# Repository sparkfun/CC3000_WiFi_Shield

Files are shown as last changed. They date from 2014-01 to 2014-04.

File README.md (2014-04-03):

CC3000_WiFi_Shield
====================

[TI CC3000 WiFi Shield  
*CC3000 WiFi Shield (WRL-12071)*](https://www.sparkfun.com/products/12071)

Arduino WiFi shield for the [TI CC3000 module](http://www.ti.com/product/cc3000). The datasheet can be found [here](http://www.ti.com/lit/ds/symlink/cc3000.pdf).

Arduino library and examples can be found in the [SFE_CC3000_Library](https://github.com/sparkfun/SFE_CC3000_Library).

This part was created in Eagle v6.5.0. Example sketches were created in Arduino v1.0.5.

Repository Contents
-------------------

* **/Hardware** - All Eagle design files (.brd, .sch, .STL)
* **/Production** - Test bed files and production panel files

Version History
---------------
* **v1.0** Initial release

License Information
-------------------
The hardware is released under [Creative Commons Share-alike 3.0](http://creativecommons.org/licenses/by-sa/3.0/).  
All other code is open source so please feel free to do anything you want with it; you buy me a beer if you use this and we meet someday ([Beerware license](http://en.wikipedia.org/wiki/Beerware)).

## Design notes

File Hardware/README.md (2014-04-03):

# What Are these Files?

The .sch and .brd files hare are Eagle CAD schematic and PCB design files.

These files were created with Eagle 6.5.0, you'll need Eagle 6.5 or later to open them up. There is a free, lite, version of Eagle available from [cadsoftusa.com](cadsoftusa.com).

# License

This product is open source! These Eagle files are released under the Creative Commons Share-Alike Attribution license ([CC BY-SA 3.0](http://creativecommons.org/licenses/by-sa/3.0/us/)).

Please use, reuse, and modify these files as you see fit. Please maintain attribution and release anything derivative under the same license.

- Your friends at SparkFun.

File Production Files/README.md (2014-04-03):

These are the production files SparkFun uses for printing PCBs, as well as the Eagle files for our test beds.

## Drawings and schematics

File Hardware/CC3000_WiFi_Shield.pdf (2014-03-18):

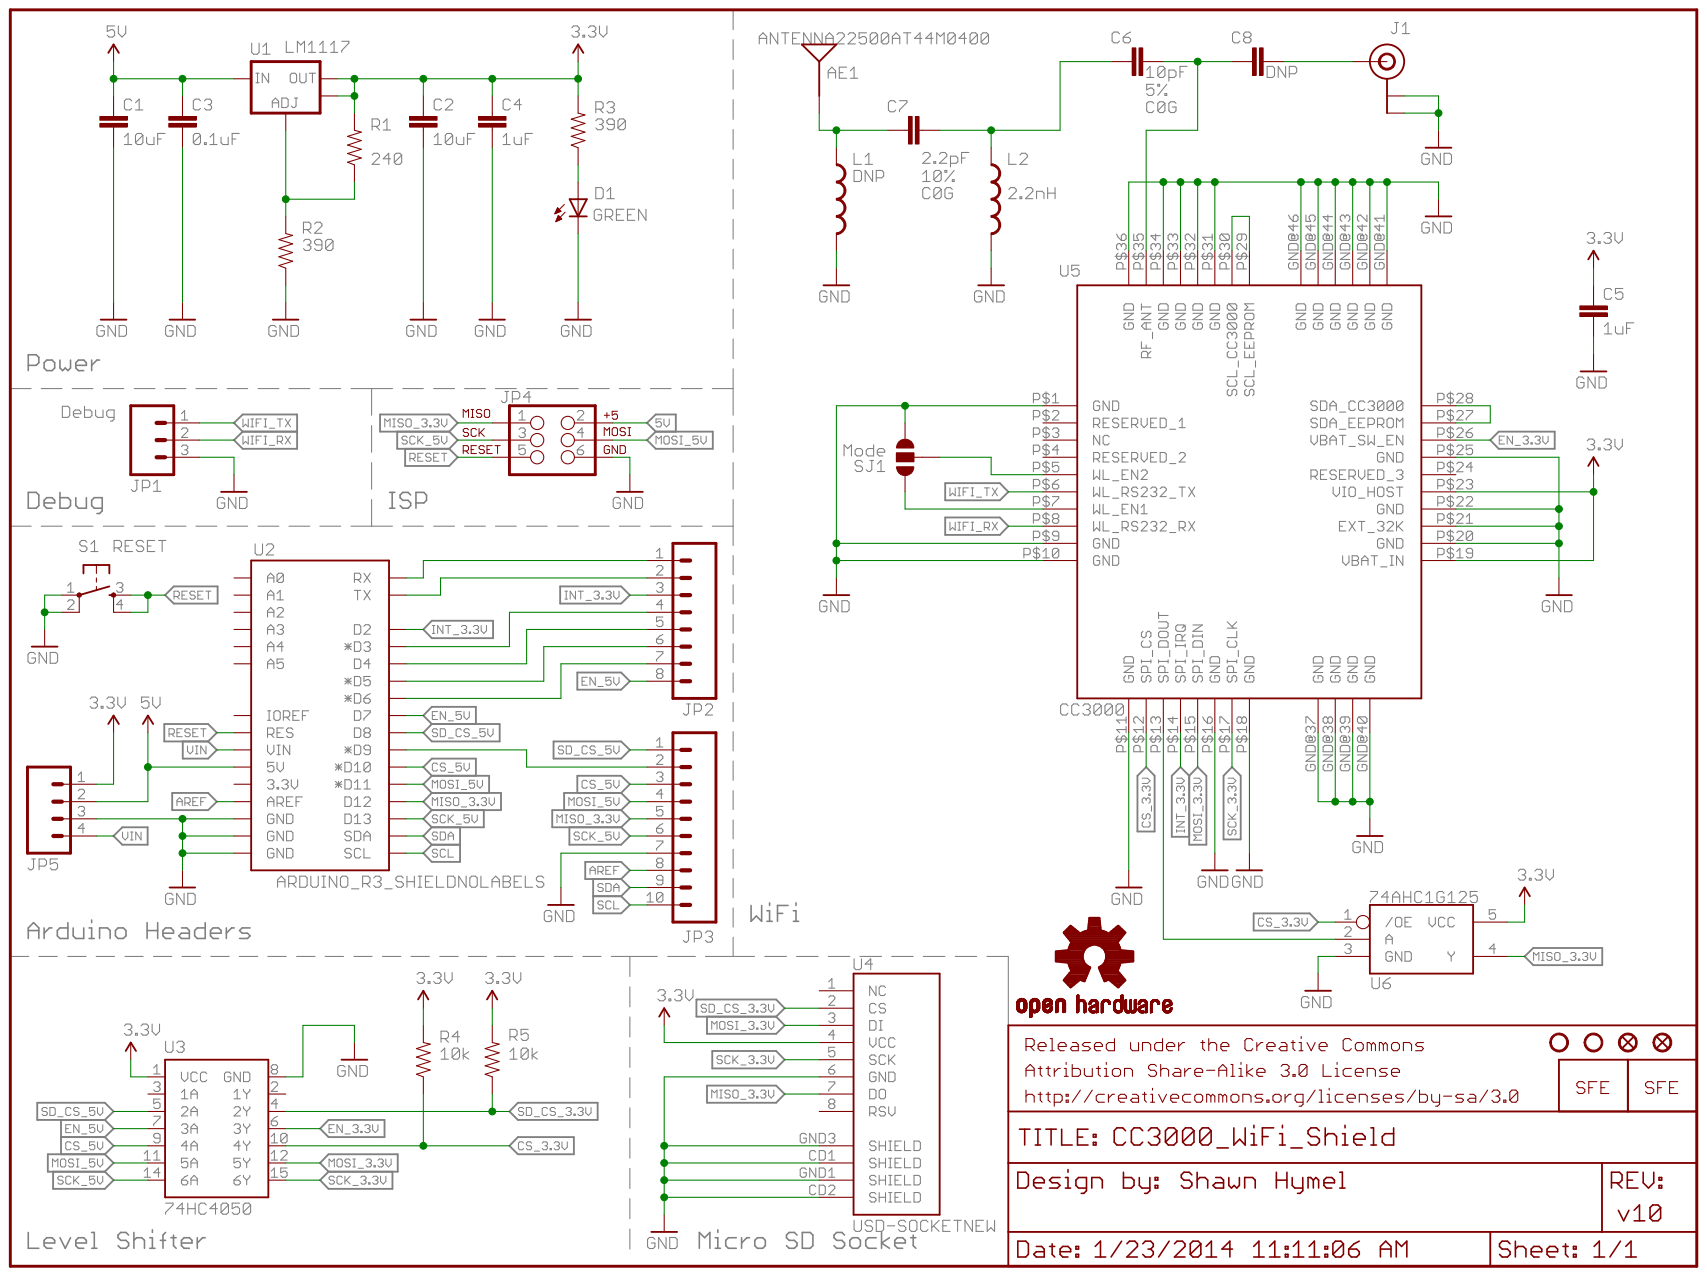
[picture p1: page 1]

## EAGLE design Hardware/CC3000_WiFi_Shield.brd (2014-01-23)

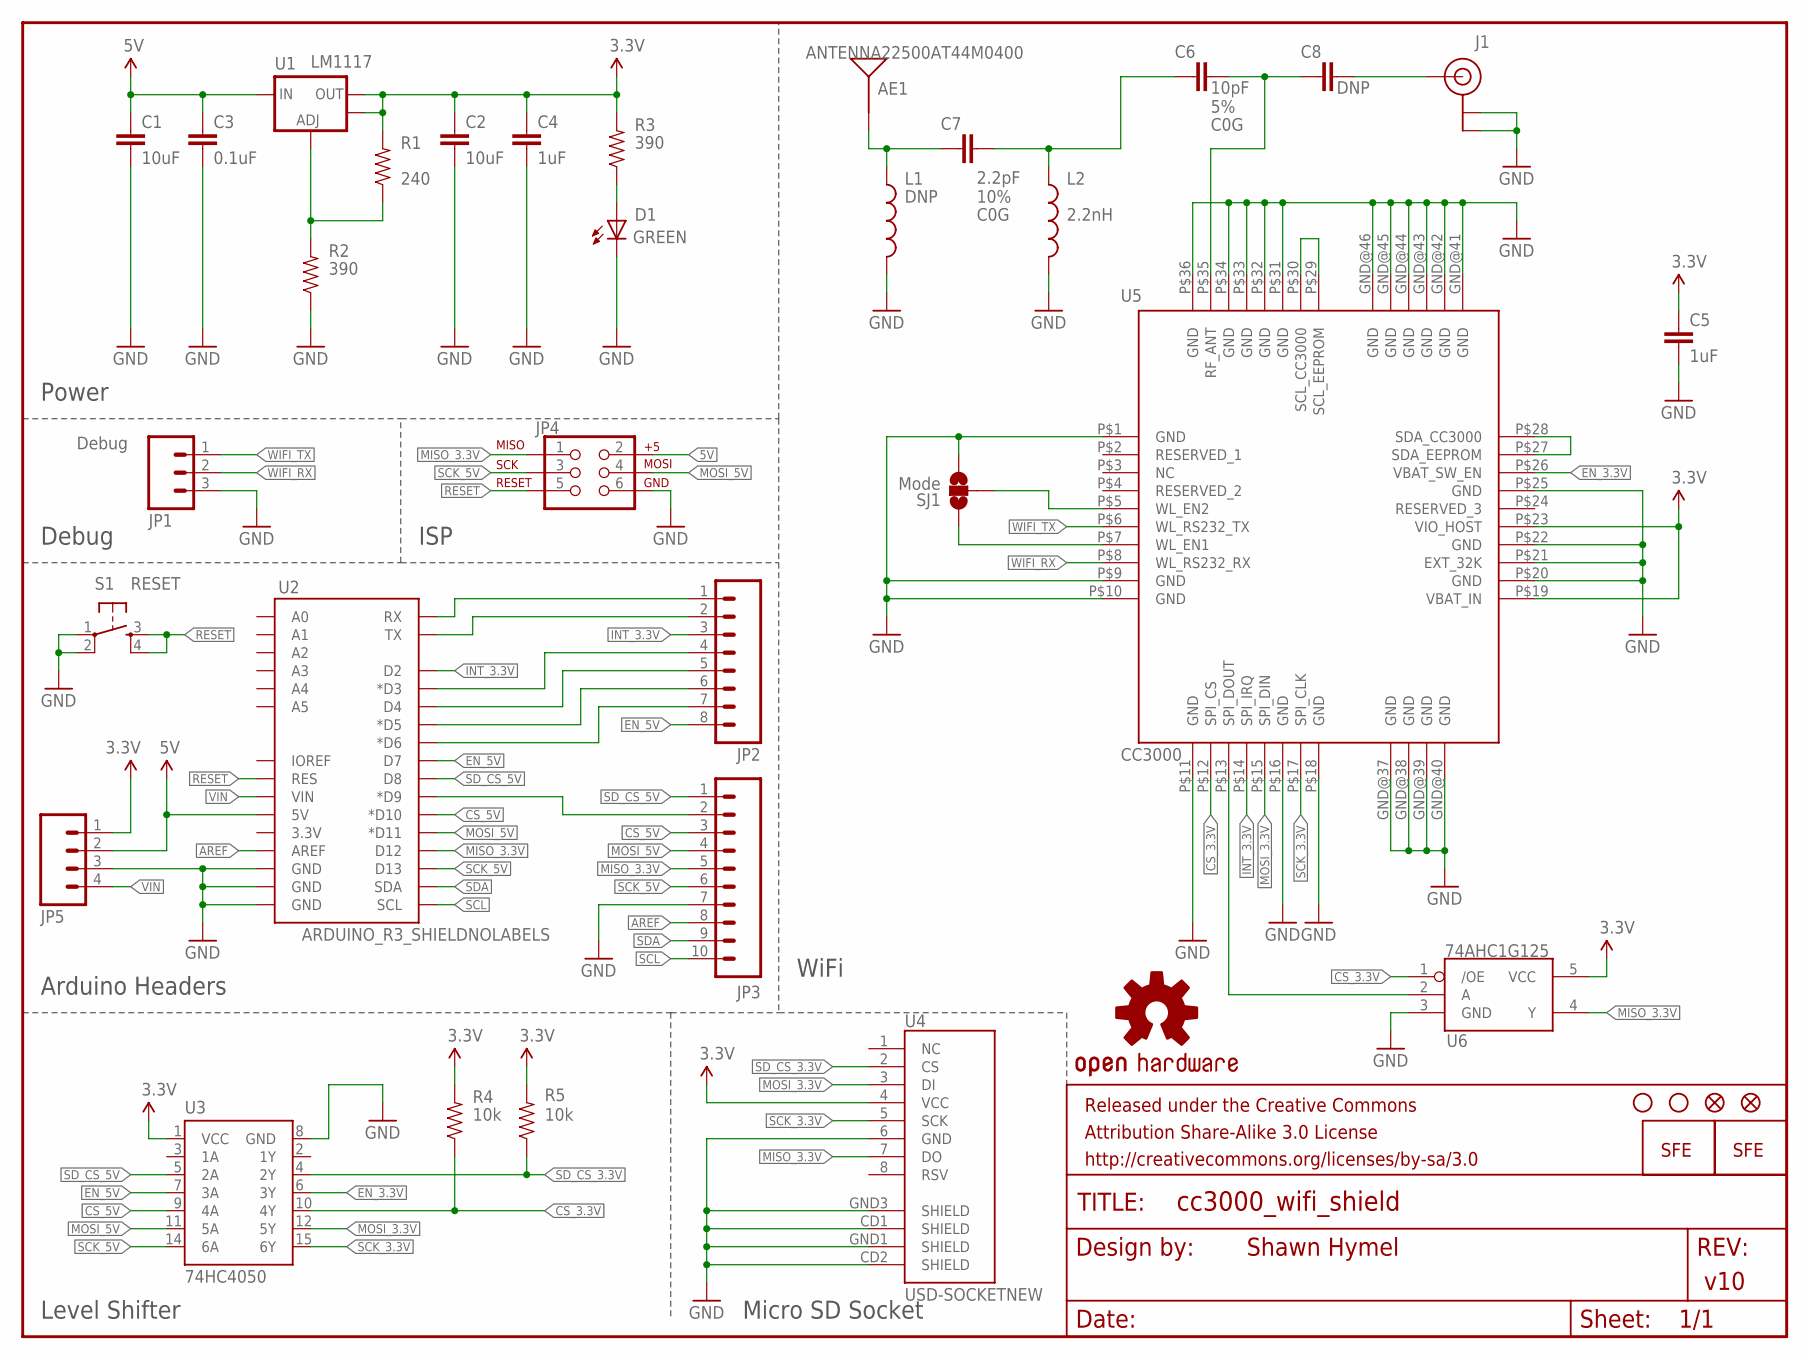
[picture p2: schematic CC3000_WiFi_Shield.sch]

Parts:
AE1: ANTENNA22500AT44M0400; ANTENNA-CHIP_2500AT44M0400
C1, C2: 10uF; 0805
C3: 0.1uF; 0603-CAP
C4, C5: 1uF; 0805
C6: 10pF; 0603-CAP
C7: 2.2pF; 0603-CAP
C8: DNP; 0603-CAP
D1: GREEN; LED-0603
FID1, FID2: FIDUCIAL1X2; FIDUCIAL-1X2
FRAME1: FRAME-LETTER; CREATIVE_COMMONS
J1: U.FL
JP1: Debug; 1X03
JP2: M08NO_SILK; 1X08_NO_SILK
JP3: M10NO_SILK; 1X10_NO_SILK
JP4: AVR_SPI_PRG_6PTH; 2X3
JP5: M04PTH; 1X04
L1: DNP; 0603
L2: 2.2nH; 0603
LOGO1: OSHW-LOGOS; OSHW-LOGO-S
LOGO2: LOGO-SFENEW; SFE-NEW-WEBLOGO
LOGO3: LOGO-SFESK; SFE-LOGO-FLAME
R1: 240; 0603-RES
R2, R3: 390; 0603-RES
R4, R5: 10k; 0603-RES
S1: RESET; TACTILE_SWITCH_SMD
SJ1: Mode; SJ_3_PASTE1&2
STANDOFF1, STANDOFF2: STAND-OFF
U1: LM1117; SOT223
U2: ARDUINO_R3_SHIELDNOLABELS; UNO_R3_SHIELD_NOLABELS
U3: 74HC4050; SO016
U4: USD-SOCKETNEW; MICRO-SD-SOCKET-PP
U5: CC3000; QFN-46_CC3000
U6: 74AHC1G125; SOT23-5

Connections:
3.3V: C2.1, C4.1, C5.1, JP5.1, R1.2, R3.2, R4.2, R5.2, U1.2 (OUT), U1.4 (OUT), U3.1 (VCC), U4.4 (VCC), U5.P$19 (VBAT_IN), U5.P$23 (VIO_HOST), U6.5 (VCC)
5V: C1.1, C3.1, JP4.2, JP5.2, U1.3 (IN), U2.5V
AREF: JP3.8, U2.AREF
CS_3.3V: R4.1, U3.10 (4Y), U5.P$12 (SPI_CS), U6.1 (/OE)
CS_5V: JP3.3, U2.D10 (*D10), U3.9 (4A)
EN_3.3V: U3.6 (3Y), U5.P$26 (VBAT_SW_EN)
EN_5V: JP2.8, U2.D7, U3.7 (3A)
GND: C1.2, C2.2, C3.2, C4.2, C5.2, D1.C, J1.P$1 (GND), J1.P$2 (GND), JP1.3, JP3.7, JP4.6, JP5.3, L1.2, L2.2, R2.1, S1.1, S1.2, SJ1.3, U2.GND@0 (GND), U2.GND@1 (GND), U2.GND@2 (GND), U3.8 (GND), U4.6 (GND), U4.CD1 (SHIELD), U4.CD2 (SHIELD), U4.GND1 (SHIELD), U4.GND3 (SHIELD), U5.GND@37 (GND), U5.GND@38 (GND), U5.GND@39 (GND), U5.GND@40 (GND), U5.GND@41 (GND), U5.GND@42 (GND), U5.GND@43 (GND), U5.GND@44 (GND), U5.GND@45 (GND), U5.GND@46 (GND), U5.P$1 (GND), U5.P$9 (GND), U5.P$10 (GND), U5.P$11 (GND), U5.P$16 (GND), U5.P$18 (GND), U5.P$20 (GND), U5.P$21 (EXT_32K), U5.P$22 (GND), U5.P$25 (GND), U5.P$31 (GND), U5.P$32 (GND), U5.P$33 (GND), U5.P$34 (GND), U5.P$36 (GND), U6.3 (GND)
INT_3.3V: JP2.3, U2.D2, U5.P$14 (SPI_IRQ)
MISO_3.3V: JP3.5, JP4.1, U2.D12, U4.7 (DO), U6.4 (Y)
MOSI_3.3V: U3.12 (5Y), U4.3 (DI), U5.P$15 (SPI_DIN)
MOSI_5V: JP3.4, JP4.4, U2.D11 (*D11), U3.11 (5A)
unnamed: R1.1, R2.2, U1.1 (ADJ)
unnamed: SJ1.2, U5.P$5 (WL_EN2)
unnamed: SJ1.1, U5.P$7 (WL_EN1)
unnamed: C6.1, C7.2, L2.1
unnamed: U5.P$27 (SDA_EEPROM), U5.P$28 (SDA_CC3000)
unnamed: U5.P$29 (SCL_EEPROM), U5.P$30 (SCL_CC3000)
unnamed: C6.2, C8.1, U5.P$35 (RF_ANT)
unnamed: C8.2, J1.P$3 (SIGNAL)
unnamed: AE1.FEED, C7.1, L1.1
unnamed: D1.A, R3.1
unnamed: JP2.1, U2.RX
unnamed: JP2.2, U2.TX
unnamed: JP2.4, U2.D3 (*D3)
unnamed: JP2.6, U2.D5 (*D5)
unnamed: JP2.7, U2.D6 (*D6)
unnamed: JP2.5, U2.D4
unnamed: JP3.2, U2.D9 (*D9)
RESET: JP4.5, S1.3, S1.4, U2.RES
SCK_3.3V: U3.15 (6Y), U4.5 (SCK), U5.P$17 (SPI_CLK)
SCK_5V: JP3.6, JP4.3, U2.D13, U3.14 (6A)
SCL: JP3.10, U2.SCL
SDA: JP3.9, U2.SDA
SD_CS_3.3V: R5.1, U3.4 (2Y), U4.2 (CS)
SD_CS_5V: JP3.1, U2.D8, U3.5 (2A)
VIN: JP5.4, U2.VIN
WIFI_MISO: U5.P$13 (SPI_DOUT), U6.2 (A)
WIFI_RX: JP1.2, U5.P$8 (WL_RS232_RX)
WIFI_TX: JP1.1, U5.P$6 (WL_RS232_TX)

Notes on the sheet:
Shawn Hymel
v10
Power
Debug
Arduino Headers
Level Shifter
Micro SD Socket
WiFi
ISP

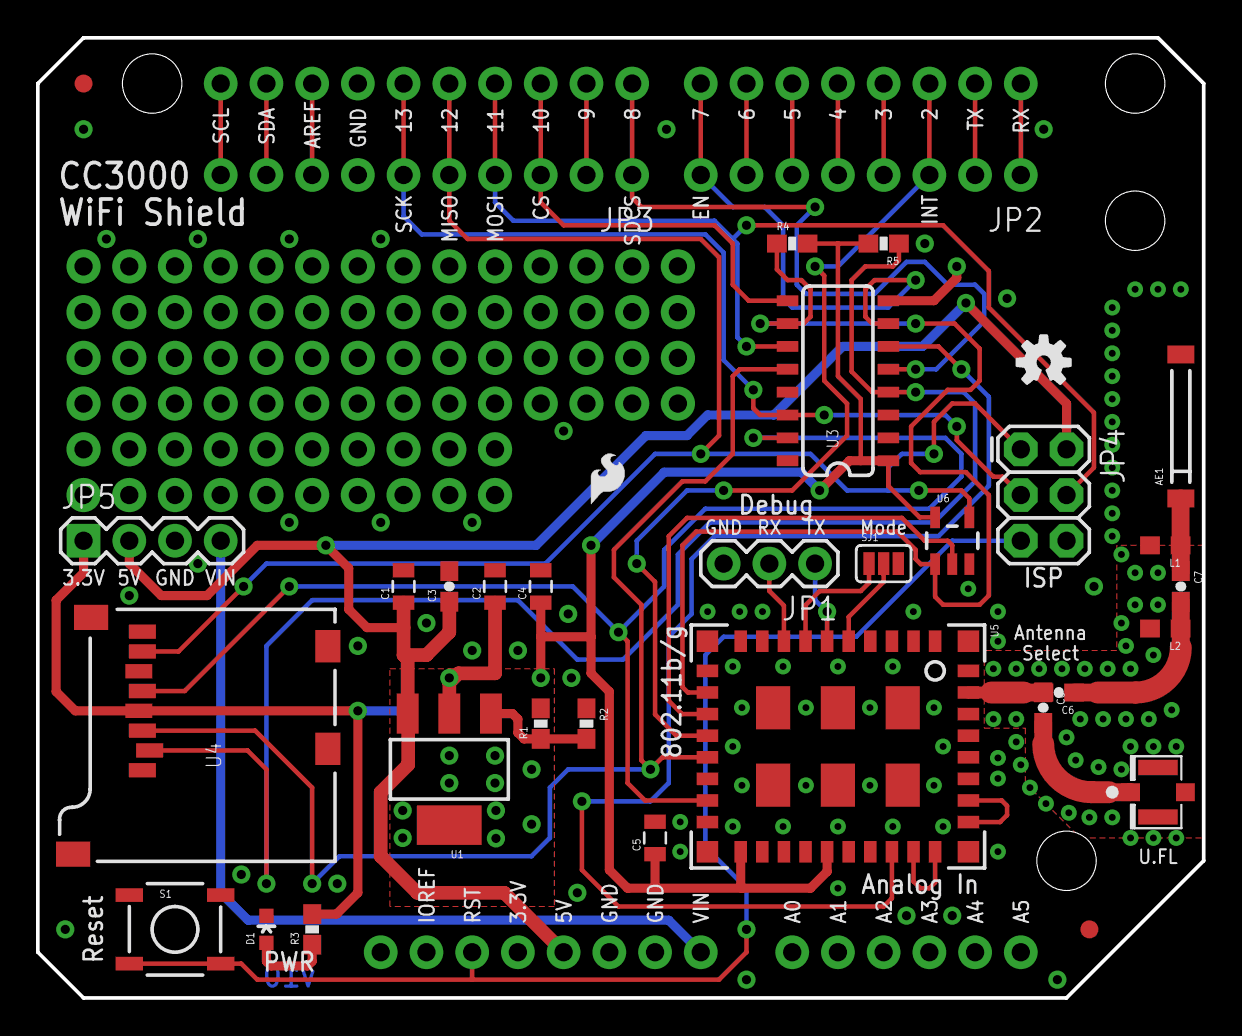
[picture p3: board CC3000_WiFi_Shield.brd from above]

Board: 2 copper layers, 64.8 x 53.3 mm, 39 parts (1 on the bottom side), 40 nets.

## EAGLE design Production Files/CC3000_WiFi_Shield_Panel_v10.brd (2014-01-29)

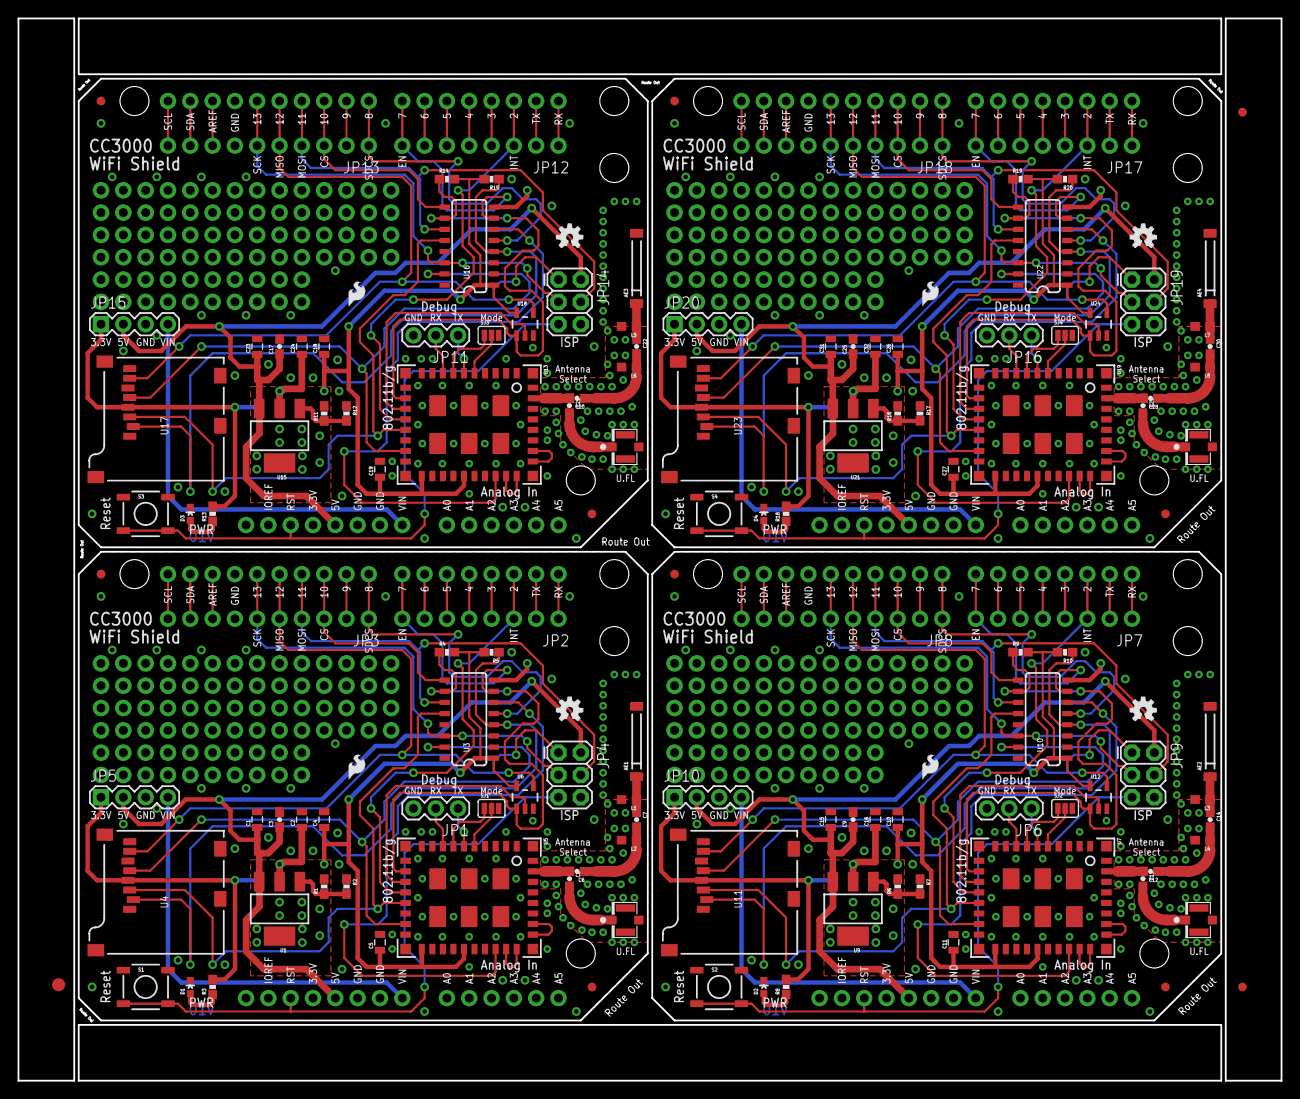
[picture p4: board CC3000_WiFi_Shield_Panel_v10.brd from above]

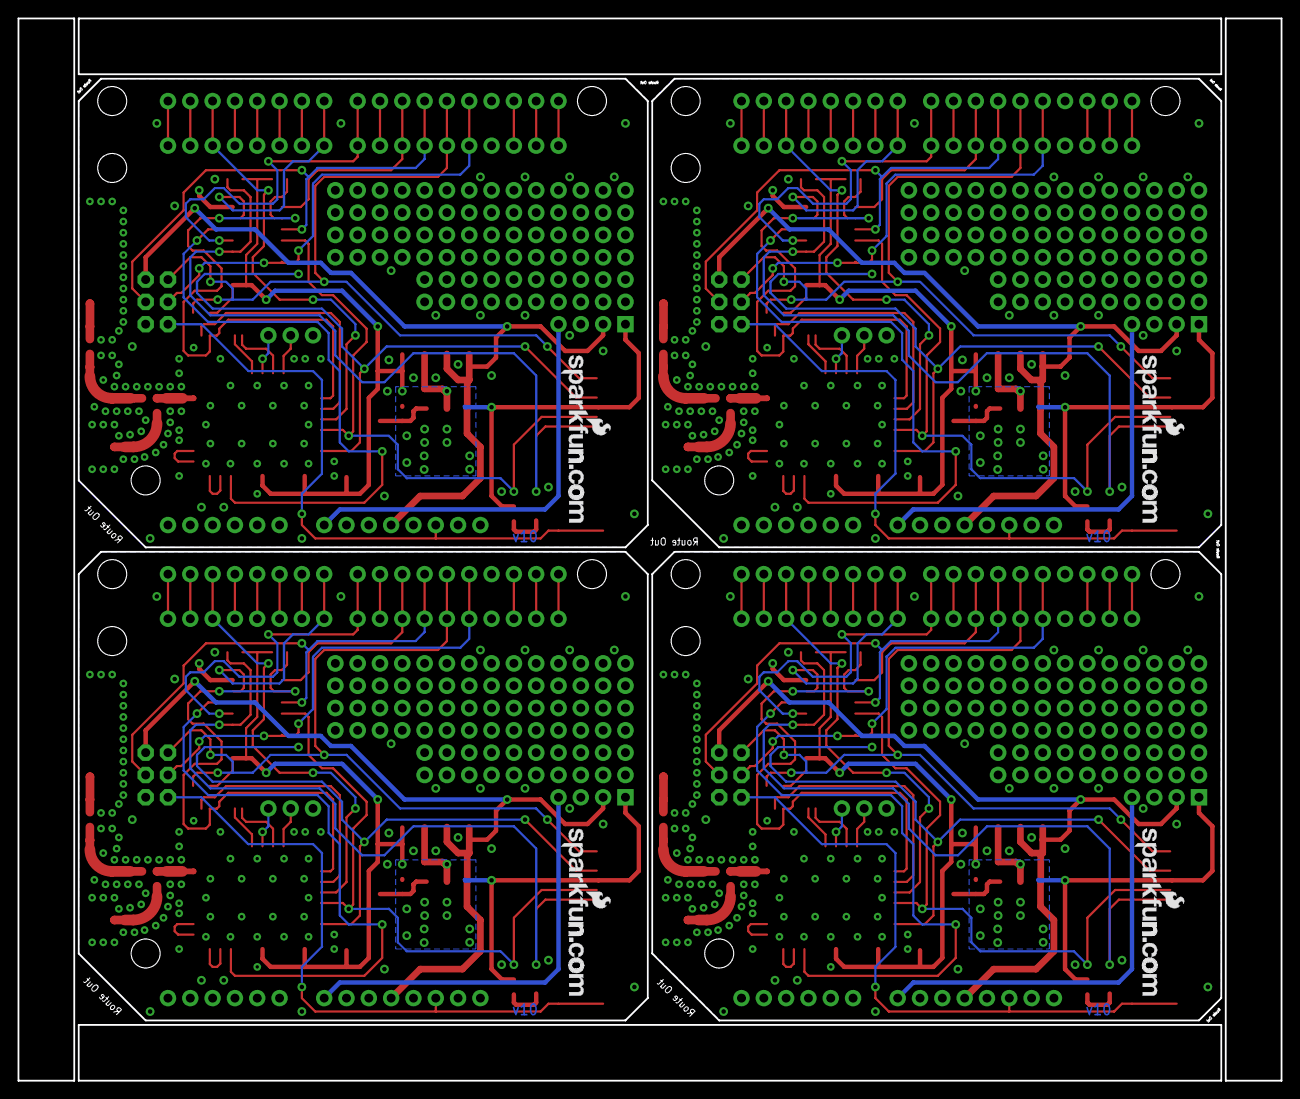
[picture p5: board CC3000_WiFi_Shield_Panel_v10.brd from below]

Board: 2 copper layers, 143.8 x 120.9 mm, 155 parts (4 on the bottom side), 160 nets.

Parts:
AE1, AE2, AE3, AE4: ANTENNA22500AT44M0400; ANTENNA-CHIP_2500AT44M0400
C1, C2, C15, C16, C23, C24, C31, C32: 10uF; 0805
C3, C9, C17, C25: 0.1uF; 0603-CAP
C4, C5, C10, C11, C18, C19, C26, C27: 1uF; 0805
C6, C12, C20, C28: 10pF; 0603-CAP
C7, C14, C22, C30: 2.2pF; 0603-CAP
C8, C13, C21, C29: DNP; 0603-CAP
D1, D2, D3, D4: GREEN; LED-0603
E$1: FIDUCIAL-1.5X3
E$4, E$5: FIDUCIAL-1X2
FID1, FID2, FID3, FID4, FID5, FID6, FID7, FID8: FIDUCIAL1X2; FIDUCIAL-1X2
J1, J2, J3, J4: U.FL
JP1, JP6, JP11, JP16: Debug; 1X03
JP2, JP7, JP12, JP17: 1X08_NO_SILK
JP3, JP8, JP13, JP18: M10NO_SILK; 1X10_NO_SILK
JP4, JP9, JP14, JP19: AVR_SPI_PRG_6PTH; 2X3
JP5, JP10, JP15, JP20: 1X04
L1, L3, L5, L7: DNP; 0603
L2, L4, L6, L8: 2.2nH; 0603
LOGO1, LOGO4, LOGO7, LOGO10: OSHW-LOGOS; OSHW-LOGO-S
LOGO2, LOGO5, LOGO8, LOGO11: LOGO-SFENEW; SFE-NEW-WEBLOGO
LOGO3, LOGO6, LOGO9, LOGO12: LOGO-SFESK; SFE-LOGO-FLAME
R1, R6, R11, R16: 240; 0603-RES
R2, R3, R7, R8, R12, R13, R17, R18: 390; 0603-RES
R4, R5, R9, R10, R14, R15, R19, R20: 10k; 0603-RES
S1, S2, S3, S4: RESET; TACTILE_SWITCH_SMD
SJ1, SJ2, SJ3, SJ4: Mode; SJ_3_PASTE1&2
STANDOFF1, STANDOFF2, STANDOFF3, STANDOFF4, STANDOFF5, STANDOFF6, STANDOFF7, STANDOFF8: STAND-OFF
U1, U9, U15, U21: LM1117; SOT223
U2, U8, U14, U20: ARDUINO_R3_SHIELDNOLABELS; UNO_R3_SHIELD_NOLABELS
U3, U10, U16, U22: 74HC4050; SO016
U4, U11, U17, U23: USD-SOCKETNEW; MICRO-SD-SOCKET-PP
U5, U7, U13, U19: CC3000; QFN-46_CC3000
U6, U12, U18, U24: 74AHC1G125; SOT23-5

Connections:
3.3V: C2.1, C4.1, C5.1, JP5.1, R1.2, R3.2, R4.2, R5.2, U1.2, U1.4, U3.1, U4.4, U5.P$19, U5.P$23, U6.5
3.3V1: C10.1, C11.1, C16.1, JP10.1, R6.2, R8.2, R9.2, R10.2, U7.P$19, U7.P$23, U9.2, U9.4, U10.1, U11.4, U12.5
3.3V2: C18.1, C19.1, C24.1, JP15.1, R11.2, R13.2, R14.2, R15.2, U13.P$19, U13.P$23, U15.2, U15.4, U16.1, U17.4, U18.5
3.3V3: C26.1, C27.1, C32.1, JP20.1, R16.2, R18.2, R19.2, R20.2, U19.P$19, U19.P$23, U21.2, U21.4, U22.1, U23.4, U24.5
5V: C1.1, C3.1, JP4.2, JP5.2, U1.3, U2.5V
5V1: C9.1, C15.1, JP9.2, JP10.2, U8.5V, U9.3
5V2: C17.1, C23.1, JP14.2, JP15.2, U14.5V, U15.3
5V3: C25.1, C31.1, JP19.2, JP20.2, U20.5V, U21.3
AREF: JP3.8, U2.AREF
AREF1: JP8.8, U8.AREF
AREF2: JP13.8, U14.AREF
AREF3: JP18.8, U20.AREF
CS_3.3V: R4.1, U3.10, U5.P$12, U6.1
CS_3.3V1: R9.1, U7.P$12, U10.10, U12.1
CS_3.3V2: R14.1, U13.P$12, U16.10, U18.1
CS_3.3V3: R19.1, U19.P$12, U22.10, U24.1
CS_5V: JP3.3, U2.D10, U3.9
CS_5V1: JP8.3, U8.D10, U10.9
CS_5V2: JP13.3, U14.D10, U16.9
CS_5V3: JP18.3, U20.D10, U22.9
EN_3.3V: U3.6, U5.P$26
EN_3.3V1: U7.P$26, U10.6
EN_3.3V2: U13.P$26, U16.6
EN_3.3V3: U19.P$26, U22.6
EN_5V: JP2.8, U2.D7, U3.7
EN_5V1: JP7.8, U8.D7, U10.7
EN_5V2: JP12.8, U14.D7, U16.7
EN_5V3: JP17.8, U20.D7, U22.7
GND: C1.2, C2.2, C3.2, C4.2, C5.2, D1.C, J1.P$1, J1.P$2, JP1.3, JP3.7, JP4.6, JP5.3, L1.2, L2.2, R2.1, S1.1, S1.2, SJ1.3, U2.GND@0, U2.GND@1, U2.GND@2, U3.8, U4.6, U4.CD1, U4.CD2, U4.GND1, U4.GND3, U5.GND@37, U5.GND@38, U5.GND@39, U5.GND@40, U5.GND@41, U5.GND@42, U5.GND@43, U5.GND@44, U5.GND@45, U5.GND@46, U5.P$1, U5.P$9, U5.P$10, U5.P$11, U5.P$16, U5.P$18, U5.P$20, U5.P$21, U5.P$22, U5.P$25, U5.P$31, U5.P$32, U5.P$33, U5.P$34, U5.P$36, U6.3
GND1: C9.2, C10.2, C11.2, C15.2, C16.2, D2.C, J2.P$1, J2.P$2, JP6.3, JP8.7, JP9.6, JP10.3, L3.2, L4.2, R7.1, S2.1, S2.2, SJ2.3, U7.GND@37, U7.GND@38, U7.GND@39, U7.GND@40, U7.GND@41, U7.GND@42, U7.GND@43, U7.GND@44, U7.GND@45, U7.GND@46, U7.P$1, U7.P$9, U7.P$10, U7.P$11, U7.P$16, U7.P$18, U7.P$20, U7.P$21, U7.P$22, U7.P$25, U7.P$31, U7.P$32, U7.P$33, U7.P$34, U7.P$36, U8.GND@0, U8.GND@1, U8.GND@2, U10.8, U11.6, U11.CD1, U11.CD2, U11.GND1, U11.GND3, U12.3
GND2: C17.2, C18.2, C19.2, C23.2, C24.2, D3.C, J3.P$1, J3.P$2, JP11.3, JP13.7, JP14.6, JP15.3, L5.2, L6.2, R12.1, S3.1, S3.2, SJ3.3, U13.GND@37, U13.GND@38, U13.GND@39, U13.GND@40, U13.GND@41, U13.GND@42, U13.GND@43, U13.GND@44, U13.GND@45, U13.GND@46, U13.P$1, U13.P$9, U13.P$10, U13.P$11, U13.P$16, U13.P$18, U13.P$20, U13.P$21, U13.P$22, U13.P$25, U13.P$31, U13.P$32, U13.P$33, U13.P$34, U13.P$36, U14.GND@0, U14.GND@1, U14.GND@2, U16.8, U17.6, U17.CD1, U17.CD2, U17.GND1, U17.GND3, U18.3
GND3: C25.2, C26.2, C27.2, C31.2, C32.2, D4.C, J4.P$1, J4.P$2, JP16.3, JP18.7, JP19.6, JP20.3, L7.2, L8.2, R17.1, S4.1, S4.2, SJ4.3, U19.GND@37, U19.GND@38, U19.GND@39, U19.GND@40, U19.GND@41, U19.GND@42, U19.GND@43, U19.GND@44, U19.GND@45, U19.GND@46, U19.P$1, U19.P$9, U19.P$10, U19.P$11, U19.P$16, U19.P$18, U19.P$20, U19.P$21, U19.P$22, U19.P$25, U19.P$31, U19.P$32, U19.P$33, U19.P$34, U19.P$36, U20.GND@0, U20.GND@1, U20.GND@2, U22.8, U23.6, U23.CD1, U23.CD2, U23.GND1, U23.GND3, U24.3
INT_3.3V: JP2.3, U2.D2, U5.P$14
INT_3.3V1: JP7.3, U7.P$14, U8.D2
INT_3.3V2: JP12.3, U13.P$14, U14.D2
INT_3.3V3: JP17.3, U19.P$14, U20.D2
MISO_3.3V: JP3.5, JP4.1, U2.D12, U4.7, U6.4
MISO_3.3V1: JP8.5, JP9.1, U8.D12, U11.7, U12.4
MISO_3.3V2: JP13.5, JP14.1, U14.D12, U17.7, U18.4
MISO_3.3V3: JP18.5, JP19.1, U20.D12, U23.7, U24.4
MOSI_3.3V: U3.12, U4.3, U5.P$15
MOSI_3.3V1: U7.P$15, U10.12, U11.3
MOSI_3.3V2: U13.P$15, U16.12, U17.3
MOSI_3.3V3: U19.P$15, U22.12, U23.3
MOSI_5V: JP3.4, JP4.4, U2.D11, U3.11
MOSI_5V1: JP8.4, JP9.4, U8.D11, U10.11
MOSI_5V2: JP13.4, JP14.4, U14.D11, U16.11
MOSI_5V3: JP18.4, JP19.4, U20.D11, U22.11
unnamed: R6.1, R7.2, U9.1
unnamed: R1.1, R2.2, U1.1
unnamed: SJ1.2, U5.P$5
unnamed: SJ1.1, U5.P$7
unnamed: C6.1, C7.2, L2.1
unnamed: U5.P$27, U5.P$28
unnamed: U5.P$29, U5.P$30
unnamed: C6.2, C8.1, U5.P$35
unnamed: C8.2, J1.P$3
unnamed: AE1.FEED, C7.1, L1.1
unnamed: D1.A, R3.1
unnamed: SJ2.2, U7.P$5
unnamed: SJ2.1, U7.P$7
unnamed: U7.P$27, U7.P$28
unnamed: U7.P$29, U7.P$30
unnamed: C12.1, C14.2, L4.1
unnamed: AE2.FEED, C14.1, L3.1
unnamed: C13.2, J2.P$3
unnamed: D2.A, R8.1
unnamed: JP2.1, U2.RX
unnamed: JP2.2, U2.TX
unnamed: JP2.4, U2.D3
unnamed: JP2.6, U2.D5
unnamed: JP2.7, U2.D6
unnamed: JP2.5, U2.D4
unnamed: JP3.2, U2.D9
unnamed: C12.2, C13.1, U7.P$35
unnamed: JP7.4, U8.D3
unnamed: JP7.6, U8.D5
unnamed: JP7.7, U8.D6
unnamed: JP7.1, U8.RX
unnamed: JP7.2, U8.TX
unnamed: JP8.2, U8.D9
unnamed: JP7.5, U8.D4
unnamed: R11.1, R12.2, U15.1
unnamed: SJ3.2, U13.P$5
unnamed: SJ3.1, U13.P$7
unnamed: U13.P$27, U13.P$28
unnamed: U13.P$29, U13.P$30
unnamed: C20.1, C22.2, L6.1
unnamed: AE3.FEED, C22.1, L5.1
unnamed: C21.2, J3.P$3
unnamed: D3.A, R13.1
unnamed: C20.2, C21.1, U13.P$35
unnamed: JP12.4, U14.D3
unnamed: JP12.6, U14.D5
unnamed: JP12.7, U14.D6
unnamed: JP12.1, U14.RX
unnamed: JP12.2, U14.TX
unnamed: JP13.2, U14.D9
unnamed: JP12.5, U14.D4
unnamed: R16.1, R17.2, U21.1
unnamed: SJ4.2, U19.P$5
unnamed: SJ4.1, U19.P$7
unnamed: U19.P$27, U19.P$28
unnamed: U19.P$29, U19.P$30
unnamed: C28.1, C30.2, L8.1
unnamed: AE4.FEED, C30.1, L7.1
unnamed: C29.2, J4.P$3
unnamed: D4.A, R18.1
unnamed: C28.2, C29.1, U19.P$35
unnamed: JP17.4, U20.D3
unnamed: JP17.6, U20.D5
unnamed: JP17.7, U20.D6
unnamed: JP17.1, U20.RX
unnamed: JP17.2, U20.TX
unnamed: JP18.2, U20.D9
unnamed: JP17.5, U20.D4
RESET: JP4.5, S1.3, S1.4, U2.RES
RESET1: JP9.5, S2.3, S2.4, U8.RES
RESET2: JP14.5, S3.3, S3.4, U14.RES
RESET3: JP19.5, S4.3, S4.4, U20.RES
SCK_3.3V: U3.15, U4.5, U5.P$17
SCK_3.3V1: U7.P$17, U10.15, U11.5
SCK_3.3V2: U13.P$17, U16.15, U17.5
SCK_3.3V3: U19.P$17, U22.15, U23.5
SCK_5V: JP3.6, JP4.3, U2.D13, U3.14
SCK_5V1: JP8.6, JP9.3, U8.D13, U10.14
SCK_5V2: JP13.6, JP14.3, U14.D13, U16.14
SCK_5V3: JP18.6, JP19.3, U20.D13, U22.14
SCL: JP3.10, U2.SCL
SCL1: JP8.10, U8.SCL
SCL2: JP13.10, U14.SCL
SCL3: JP18.10, U20.SCL
SDA: JP3.9, U2.SDA
SDA1: JP8.9, U8.SDA
SDA2: JP13.9, U14.SDA
SDA3: JP18.9, U20.SDA
SD_CS_3.3V: R5.1, U3.4, U4.2
SD_CS_3.3V1: R10.1, U10.4, U11.2
SD_CS_3.3V2: R15.1, U16.4, U17.2
SD_CS_3.3V3: R20.1, U22.4, U23.2
SD_CS_5V: JP3.1, U2.D8, U3.5
SD_CS_5V1: JP8.1, U8.D8, U10.5
SD_CS_5V2: JP13.1, U14.D8, U16.5
SD_CS_5V3: JP18.1, U20.D8, U22.5
VIN: JP5.4, U2.VIN
VIN1: JP10.4, U8.VIN
VIN2: JP15.4, U14.VIN
VIN3: JP20.4, U20.VIN
WIFI_MISO: U5.P$13, U6.2
WIFI_MISO1: U7.P$13, U12.2
WIFI_MISO2: U13.P$13, U18.2
WIFI_MISO3: U19.P$13, U24.2
WIFI_RX: JP1.2, U5.P$8
WIFI_RX1: JP6.2, U7.P$8
WIFI_RX2: JP11.2, U13.P$8
WIFI_RX3: JP16.2, U19.P$8
WIFI_TX: JP1.1, U5.P$6
WIFI_TX1: JP6.1, U7.P$6
WIFI_TX2: JP11.1, U13.P$6
WIFI_TX3: JP16.1, U19.P$6

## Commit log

2013-09-16 Component placement on board complete
    [CC3000_WiFi_Shield.brd, CC3000_WiFi_Shield.sch]
2013-09-17 Prototype board ready for review
    [CC3000_WiFi_Shield.brd, CC3000_WiFi_Shield.sch]
2013-09-19 Fixed floating 3.3V paddle on LM317. Made stitching vias near RF section 10 mils.
    [CC3000_WiFi_Shield.brd, CC3000_WiFi_Shield.sch]
2013-09-19 Changed stitching via size to 15 mils
    [CC3000_WiFi_Shield.brd]
2013-09-23 Ready for prototype.
    [CC3000_WiFi_Shield.brd, CC3000_WiFi_Shield.sch]
2013-12-11 Added high-Z protection on MISO, replaced tantalums, added 2nd set of headers on shield
    [CC3000_WiFi_Shield.brd, CC3000_WiFi_Shield.sch]
2013-12-12 Made corrections to schematic/board from first prototype
    [CC3000_WiFi_Shield.brd, CC3000_WiFi_Shield.sch]
2013-12-12 Board ready for review (second round of prototypes)
    [CC3000_WiFi_Shield.brd, CC3000_WiFi_Shield.sch]
2013-12-17 Added power breakout near proto area. Removed silk from shield headers. Changed silk text to 0.032 in. size. Added ISP headers to work with Leonardo. Added 10-pin shield headers to work woth UNO R3. 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
    [CC3000_WiFi_Shield.brd, CC3000_WiFi_Shield.sch]
2014-01-16 Moved ext antenna mount back 50 mil; re-routed SD_CS line to avoid splitting power plane on bottom; Added 'Antenna Select' to SS; Added SS marker to U.FL; Added 'Mode' in SS to jumper; Changed to v10
    [CC3000_WiFi_Shield.brd, CC3000_WiFi_Shield.sch]
2014-01-23 Added silk U.FL; Adjusted tvalue markings for easier reading
    [CC3000_WiFi_Shield.brd, CC3000_WiFi_Shield.sch]
2014-01-29 Created Panel
    [CC3000_WiFi_Shield_Panel_v10.brd]
2014-03-18 Added pdf of schematic

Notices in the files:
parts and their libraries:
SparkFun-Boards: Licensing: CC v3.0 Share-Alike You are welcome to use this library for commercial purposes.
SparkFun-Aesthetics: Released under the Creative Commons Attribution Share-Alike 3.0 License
